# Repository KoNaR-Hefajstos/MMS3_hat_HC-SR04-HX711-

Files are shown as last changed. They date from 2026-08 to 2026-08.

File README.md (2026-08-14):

# Hat 4x HC-SR04 i Przetwornika Tensometrycznego HX711

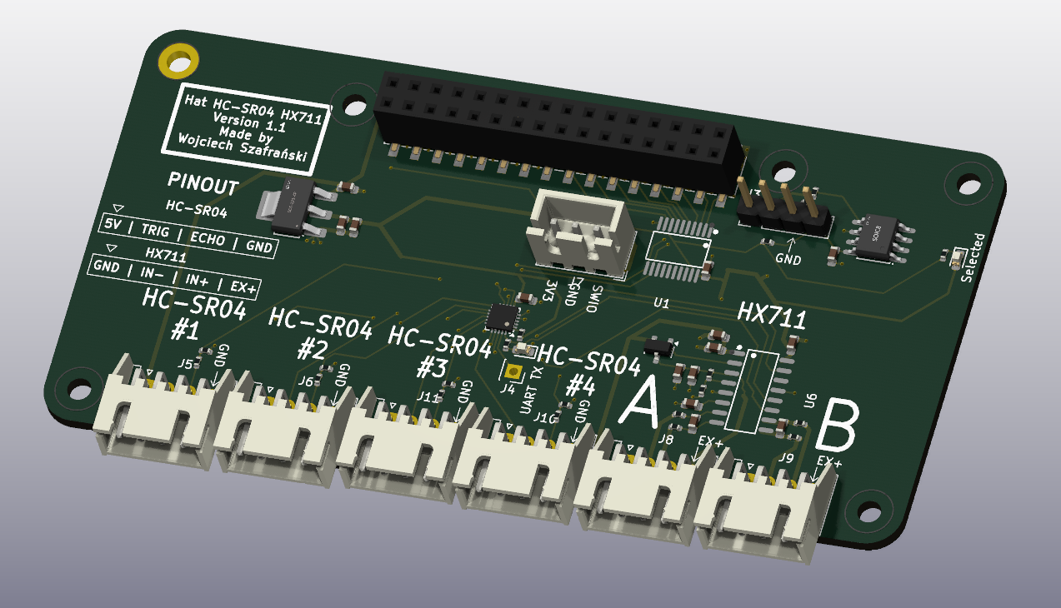
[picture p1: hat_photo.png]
zdjęcie


## Sekcja 1: Dokumentacja Hat'a

### Krótki opis projektu
Hat obsługuje cztery zewnętrzne ultradźwiękowe czujniki odległości HC-SR04 oraz dwukanałowey, 24-bitowego przetwornika dla belek tensometrycznych HX711.

Sercem modułu jest mikrokontroler **CH32V003**, który odczytuje dane z czujników i udostępnia je do odczytu po I2C

### Zgodność ze standardem ChainBus

* ✅ Używa złącza ChainBus, nie zmienia jego miejsca ani pinoutu.
* ✅ Używa wyłącznie interfejsu I2C do komunikacji zewnętrznej (działa jako Slave, nie inicjuje transmisji jako Master).
* ✅ Spełnia wymagania mechaniczne standardu (wymiary PCB, rozstaw otworów).
* ✅ Pobiera prąd mieszczący się w limitach wyznaczonych dla pojedynczego modułu (CH32V003 może wyzwalać czujniki ultradźwiękowe sekwencyjnie w celu redukcji zakłóceń i szpilek prądowych).
* ✅ Obsługuje napięcie wejściowe BRD_VIN do wartości 48V.

### Komunikacja i adresowanie

#### Adresacja I2C
Komunikacja z modułem nadrzędnym odbywa się przez magistralę I2C. Adres mikrokontrolera CH32V003 jest definiowany programowo.

| Układ (IC) | Funkcja | Adres I2C (7-bit) |
| :--- | :--- | :---: |
| **CH32V003** | Mikrokontroler (konwerter protokołów) | *Konfigurowalny w sofcie* |
| **M24C64-W** | Pamięć EEPROM (identyfikacja modułu)  | `1010000b` (0x50) |

### Pinout mikrokontrolera CH32V003

Rozprowadzenie sygnałów sterujących na piny mikrokontrolera przedstawia poniższa tabela:

| Pin MCU | Nazwa sygnału | Kierunek | Opis funkcjonalny |
| :--- | :--- | :---: | :--- |
| **PC0** | `ECHO #1` | Wejście  | Sygnał Echo z czujnika ultradźwiękowego nr 1 |
| **PC1** | `SDA` | Wej/Wyj  | Linia danych magistrali I2C (ChainBus) |
| **PC2** | `SCL` | Wejście  | Linia zegarowa magistrali I2C (ChainBus) |
| **PC3** | `TRIG #1` | Wyjście  | Sygnał wyzwalający (Trigger) dla czujnika nr 1 |
| **PC4** | `ECHO #2` | Wejście  | Sygnał Echo z czujnika ultradźwiękowego nr 2 |
| **PC5** | `TRIG #2` | Wyjście  | Sygnał wyzwalający (Trigger) dla czujnika nr 2 |
| **PC6** | `ECHO #3` | Wejście  | Sygnał Echo z czujnika ultradźwiękowego nr 3 |
| **PC7** | `TRIG #3` | Wyjście  | Sygnał wyzwalający (Trigger) dla czujnika nr 3 |
| **PD0** | `ECHO #4` | Wejście  | Sygnał Echo z czujnika ultradźwiękowego nr 4 |
| **PD2** | `TRIG #4` | Wyjście  | Sygnał wyzwalający (Trigger) dla czujnika nr 4 |
| **PD3** | `RATE_HX` | Wyjście  | Wybór prędkości próbkowania HX711 (`0` = 10 SPS, `1` = 80 SPS) |
| **PD4** | `PD_SCK_HX` | Wyjście  | Zegar transmisji oraz wyłączenie zasilania (Power Down) HX711  |
| **PD5** | `DEBUG_TX` | Wyjście  | Wyjście do debugowania (USART TX) |
| **PD6** | `DOUT_HX` | Wejście  | Wyjście danych szeregowych z przetwornika HX711 |

Dodatkowo na PD6 jest podłączona dioda, można jej użyć do debugowania
---

### Pinout złączy zewnętrznych

#### Złącza czujników ultradźwiękowych
Moduł posiada cztery  złącza w do podłączenia czujników odległości HC-SR04.

| Pin złącza | Nazwa sygnału | Opis |
| :---: | :--- | :--- |
| **1** | `5V` | Zasilanie czujnika (5V z magistrali ChainBus) |
| **2** | `TRIG` | Sygnał wyzwalający |
| **3** | `ECHO` | Sygnał powrotny |
| **4** | `GND` | Masa zasilania |

#### Złącze belki tensometrycznej (J5)
Złącze przeznaczone do podłączenia czujnika siły / wagi (belki tensometrycznej w układzie mostka Wheatstone'a). Sygnały wejściowe są dopasowane do specyfikacji Kanału B układu HX711.

| Pin złącza | Nazwa sygnału | Opis |
| :---: | :--- | :--- |
| **1** | `EX+` (E+) | Dodatnie napięcie zasilania mostka (Excitation +) |
| **2** | `INB+` | Dodatni sygnał wyjściowy z mostka (Input B+) |
| **3** | `INB-` | Ujemny sygnał wyjściowy z mostka (Input B-) |
| **4** | `GND` (E-) | Masa zasilania mostka (Excitation -) |

#### Złącze programowania mikrokontrolera (J7)
Złącze debugowania i programowania struktury CH32V003 przy użyciu WCH Link-E.

| Pin złącza | Nazwa sygnału | Opis |
| :---: | :--- | :--- |
| **1** | `SWIO` | Linia danych SWD (podłączona do pinu PD1 mikrokontrolera) |
| **2** | `GND` | Masa odniesienia |
| **3** | `3V3` | Zasilanie układu logiki (3.3V) |

---
### Szczegółowy opis działania układu

#### Sekcja ultradźwiękowa (HC-SR04)
Mikrokontroler CH32V003 cyklicznie generuje impuls wyzwalający piny `TRIG x`. Następnie mierzy czas trwania stanu wysokiego na powiązanym pinie `ECHO x`. Pomiar ten jest przeliczany na odległość zapisywany w rejestrach wewnętrznych MCU, gotowych do odczytu przez magistralę I2C.

#### Sekcja wagowa (HX711)
Układ HX711 przetwarza mikrowoltowe różnice napięć z mostka tensometrycznego na postać cyfrową.
* **Proces odczytu:** MCU monitoruje stan linii `DOUT_HX` (PD6). Gdy linia przejdzie w stan niski, oznacza to gotowość danych. Mikrokontroler taktuje linię `PD_SCK_HX` (PD4), odczytując kolejno 24 bity danych, a następnie generuje dodatkowe impulsy w celu konfiguracji następnego pomiaru (np. 26 impulsów, aby utrzymać odczyt z Kanału B ze wzmocnieniem 32).

#### Charakterystyka i parametry przetwornika HX711

Układ HX711 jest dedykowanym, 24-bitowym przetwornikiem ADC ze zintegrowanym niskoszumnym przedwzmacniaczem (PGA). Posiada on dwa różnicowe kanały wejściowe, które różnią się zakresem napięć oraz czułością:

#### Różnice między Kanałem A i Kanałem B

1. **Wzmocnienie i zakresy wejściowe (przy zasilaniu $V_{DD} = 5\text{V}$):**
   * **Kanał A:** Posiada programowalny stopień wzmocnienia równy **128** lub **64**.
     * Dla wzmocnienia **128**: zakres napięcia wejściowego wynosi **$\pm 20\text{ mV}$** (pełna skala). Jest to najbardziej czuły zakres, zalecany dla większości typowych belek tensometrycznych.
     * Dla wzmocnienia **64**: zakres napięcia wejściowego wynosi **$\pm 40\text{ mV}$**.
   * **Kanał B:** Posiada stałe, fabrycznie zdefiniowane wzmocnienie **32**.
     * Zakres napięcia wejściowego wynosi **$\pm 80\text{ mV}$**. Kanał ten, dzięki szerszemu zakresowi i mniejszej czułości, doskonale nadaje się do obsługi czujników o wyższym poziomie sygnału wyjściowego lub pomiarów pomocniczych.

2. **Wybór aktywnego kanału:**
   Multipleksacja kanałów wejściowych odbywa się programowo poprzez podanie odpowiedniej liczby impulsów zegarowych na pin `PD_SCK` po odczytaniu danych (wejście `DOUT` w stanie niskim):
   * **25 impulsów zegarowych:** następny pomiar na Kanale A ze wzmocnieniem 128,
   * **26 impulsów zegarowych:** następny pomiar na Kanale B ze wzmocnieniem 32,
   * **27 impulsów zegarowych:** następny pomiar na Kanale A ze wzmocnieniem 64.

3. **Częstotliwość próbkowania (SPS):**
   Prędkość konwersji jest ustawiana sprzętowo poprzez stan pinu `RATE_HX` (PD3):
   * Stan niski (`0`): **10 SPS** (próbek na sekundę). Zapewnia najniższy poziom szumów i najwyższą stabilność pomiarów wagowych (zalecane).
   * Stan wysoki (`1`): **80 SPS**. Zwiększa dynamikę pomiarów kosztem nieznacznego wzrostu szumu przetwornika.

---

---

### Gotowe arkusze hierarchiczne
W projekcie zaprojektowano i użyto następujących arkuszy hierarchicznych:
* **CH32v003** – Arkusz mikrokontrolera
* **Ultrasonic_HC-SR04** – Arkusz z podłączeniem HC-SR04 oraz dzielnikami napięcie 5V -> 3V3.
* **HX711_LoadCell** – Układ przetwornika HX711 ze wszytkimi elementami pasywnymi i złaczem

---

## Sekcja 2: Specyfikacja standardu ChainBus

### Architektura i łączenie modułów
Standard ChainBus umożliwia modułowe łączenie hatów. Na jednym MMS3 można zamontować pionowo **do 8 hat'ów**. Połączenie realizowane jest poprzez wpięcie złącza męskiego kolejnego hat'a w złącze żeńskie poprzedniego.

### Komunikacja i sterowanie
Magistrala ChainBus jest w pełni cyfrowa. Płyta główna nie steruje bezpośrednio sygnałami ogólnego przeznaczenia (GPIO) na poszczególnych hat'ach. Wszelkie operacje (np. odczyt czujników, sterowanie) muszą być realizowane przez dedykowane układy scalone komunikujące się przez interfejsy systemowe.

Wybór aktywnego modułu realizowany jest przez układ przełącznika magistrali (bus switch) na płycie głównej. Dzięki temu linie I2C, SPI i UART są niezależne dla każdego hat'a (brak konfliktów adresów I2C między różnymi hatami).
* **Identyfikacja:** Każdy moduł powinien posiadać pamięć EEPROM na magistrali I2C w celu identyfikacji płyty przez system - układ M24C64-W skonfigurowany na adres `1010000` przy liniach adresowych A0, A1, A2 zwartych do masy.

### Zasilanie
Złącze ChainBus dostarcza następujące linie zasilania:

| Magistrala zasilania | Napięcie znamionowe | Maksymalny prąd (łączny dla 8 hatów) | Szacowany prąd na jeden hat |
| :--- | :---: | :---: | :---: |
| **5V** | 5.0 V | 1.0 A | 125 mA |
| **12V stby** | 12.0 V | 0.5 A | 65 mA |
| **BRD_VIN** | 12.0 V – 48.0 V | 1.5 A | 185 mA |

*   Komponenty podłączone do linii `BRD_VIN` muszą być przystosowane do pracy z napięciem od 12V do **48 V**.

---

## Sekcja 3: Licencje

### Licencje projektu

*   **PCB:** CERN-OHL-P
*   **Software:** MIT License

[Template](https://github.com/KoNaR-Hefajstos/MMS3_hat_templates/) jest na licencji CC0 1.0 Universal. **Reszta projektu nie jest na tej licencji**

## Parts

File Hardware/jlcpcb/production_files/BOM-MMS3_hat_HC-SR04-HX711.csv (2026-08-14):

Comment | Designator | Footprint | LCSC | Quantity
100nF | C1,C10,C12,C13,C15,C16,C2,C6,C9 | C_0603 | C14663 | 9
100Ω | R13,R14,R15,R16 | R_0402 | C25076 | 4
10kΩ | R1,R11,R19,R21,R25,R5,R7,R9 | R_0402 | C25744 | 8
10uF | C11,C14,C3,C4,C5 | C_0603 | C19702 | 5
15kΩ | R20,R22,R6,R8 | R_0402 | C25756 | 4
20kΩ | R23 | R_0402 | C25765 | 1
330Ω | R12,R27 | R_0402 | C25104 | 2
8.2kΩ | R24 | R_0402 | C25924 | 1
AMS1117 | U3 | SOT-223-3_L6.5-W3.4-P2.30-LS7.0-BR | C6186 | 1
CH32V003F4U6 | U5 | QFN-20-1EP_3x3mm_P0.4mm_EP1.65x1.65mm | C5299908 | 1
HX711_C6705483 | U6 | SOP-16_L10.0-W3.9-P1.27-LS6.0-BL | C6705483 | 1
M24C64 | U2 | SOIC-8_L5.0-W4.0-P1.27-LS6.0-BL | C79988 | 1
MMBT3906 | Q3 | Q_SOT-23 | C7420354 | 1
Red | D3,D4 | D_0603 | C2286 | 2
SN74CB3Q3245PWR | U1 | TSSOP-20_L6.5-W4.4-P0.65-LS6.4-BL | C470961 | 1
Conn_01x04_Pin | J8 | JST_XH_S4B-XH-A_1x04_P2.50mm_Horizontal |  | 1
Debug_USART_TX | J4 | PinSocket_1x01_P2.54mm_Vertical |  | 1
Chainbus Out | J2 | PinSocket_2x16_P2.54mm_Vertical_SMD |  | 1
Conn_01x04_Pin | J3 | PinHeader_1x04_P2.54mm_Vertical |  | 1
Conn_01x04_Pin | J11 | JST_XH_S4B-XH-A_1x04_P2.50mm_Horizontal |  | 1
Conn_01x04_Pin | J10 | JST_XH_S4B-XH-A_1x04_P2.50mm_Horizontal |  | 1
Conn_01x04_Pin | J9 | JST_XH_S4B-XH-A_1x04_P2.50mm_Horizontal |  | 1
Program | J7 | JST_XH_B3B-XH-A_1x03_P2.50mm_Vertical |  | 1
Conn_01x04_Pin | J5 | JST_XH_S4B-XH-A_1x04_P2.50mm_Horizontal |  | 1
Conn_01x04_Pin | J6 | JST_XH_S4B-XH-A_1x04_P2.50mm_Horizontal |  | 1
Chainbus in | J1 | PinHeader_2x16_P2.54mm_Vertical_SMD |  | 1

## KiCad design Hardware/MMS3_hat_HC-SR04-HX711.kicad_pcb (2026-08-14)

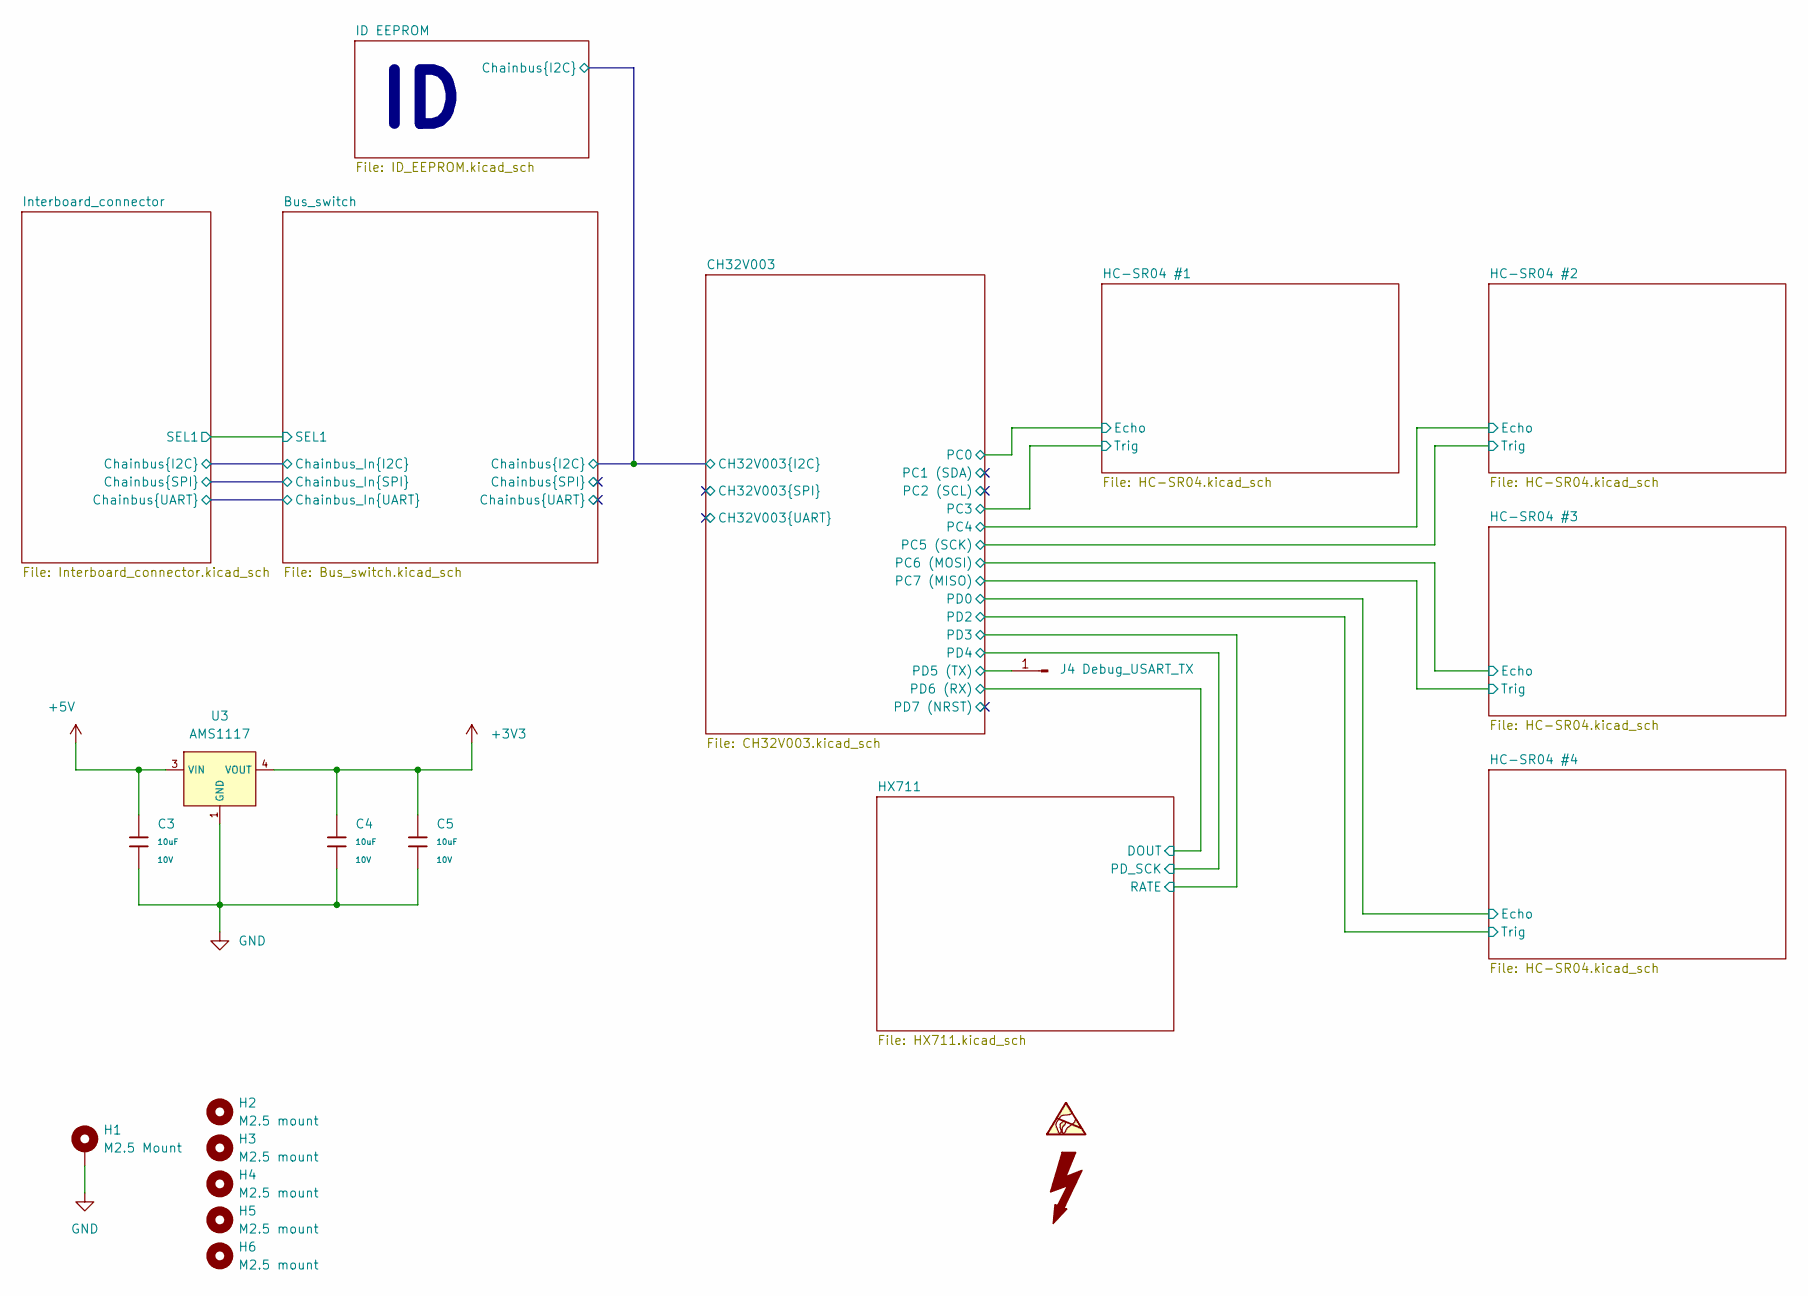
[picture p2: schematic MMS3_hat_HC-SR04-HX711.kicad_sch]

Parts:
C3, C4, C5: 10uF; C_0603; Voltage Rated 10V; Tolerance ±10%; Part CL10A106KP8NNNC; LCSC C19702
H1: M2.5 Mount; MountingHole_2.7mm_M2.5_DIN965_Pad_TopOnly
H2, H3, H4, H5, H6: M2.5 mount; MountingHole_2.7mm_M2.5
J4: Debug_USART_TX; PinSocket_1x01_P2.54mm_Vertical
U3: AMS1117; SOT-223-3_L6.5-W3.4-P2.30-LS7.0-BR; Output Voltage 3.3V; Dropout Voltage 1.3V@(800mA); Part AMS1117-3.3; LCSC C6186

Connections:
+3V3: C4.1, C5.1, U3.2 (VOUT), U3.4 (VOUT); also elsewhere on the board
+5V: C3.1, U3.3 (VIN); also elsewhere on the board
/CH32V003/CH32V003.TX: J4.1 (Pin_1_1); also elsewhere on the board
GND: C3.2, C4.2, C5.2, H1.1 (1_1), U3.1 (GND); also elsewhere on the board

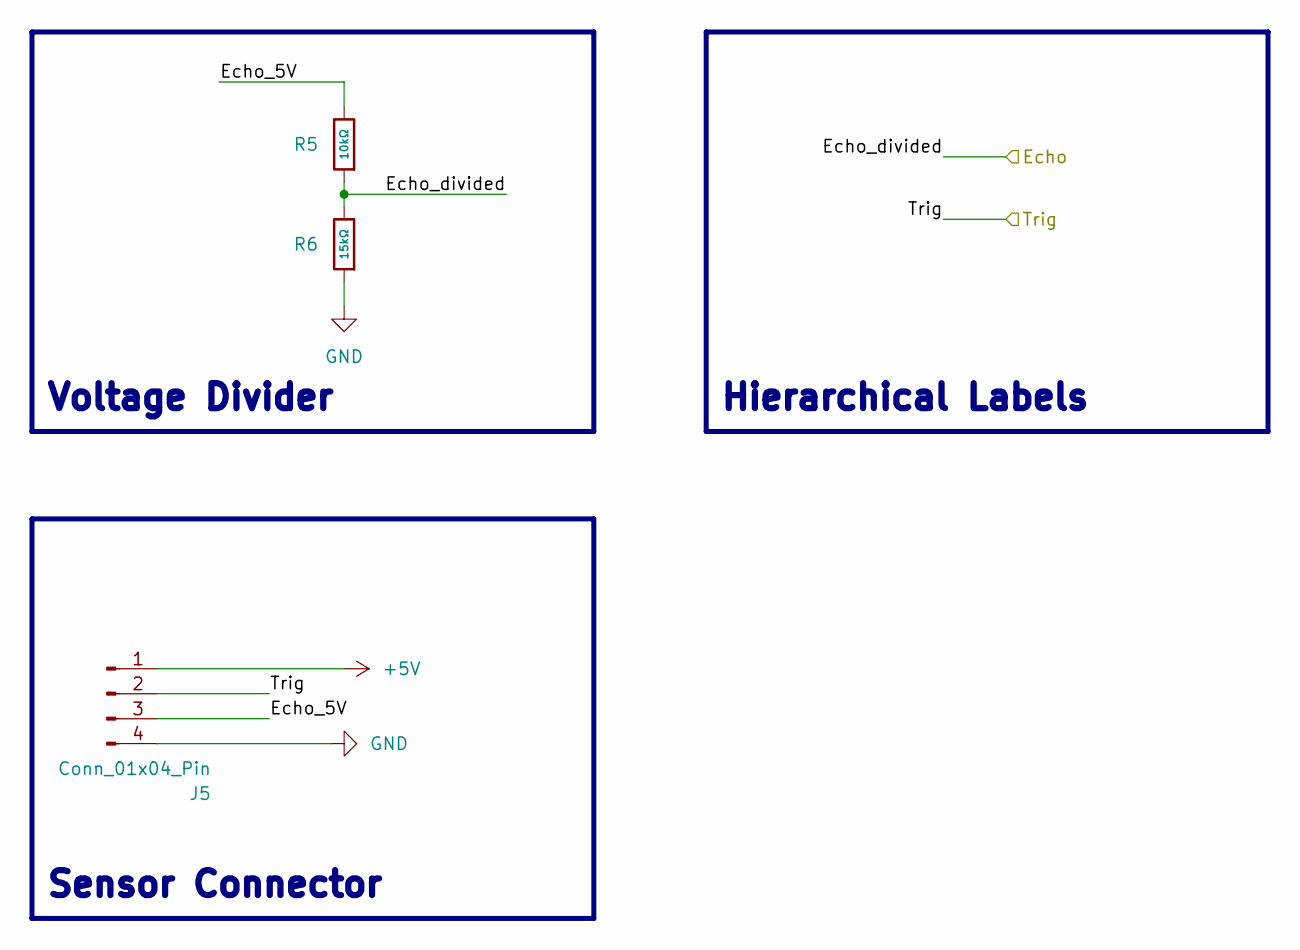
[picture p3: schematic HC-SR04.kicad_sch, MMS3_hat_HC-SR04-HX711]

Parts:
J5: Conn_01x04_Pin; JST_XH_S4B-XH-A_1x04_P2.50mm_Horizontal
R5: 10kΩ; R_0402; Overload Voltage (Max) 50V; Tolerance ±1%; Part 0402WGF1002TCE; LCSC C25744
R6: 15kΩ; R_0402; Overload Voltage (Max) 50V; Tolerance ±1%; Part 0402WGF1502TCE; LCSC C25756

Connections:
+5V: J5.1; also elsewhere on the board
/CH32V003/PC0: R5.1, R6.2; also elsewhere on the board
/CH32V003/PC3: J5.2; also elsewhere on the board
/HC-SR04 #1/Echo_5V: J5.3, R5.2
GND: J5.4, R6.1; also elsewhere on the board

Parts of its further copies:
J6, J10, J11: Conn_01x04_Pin; JST_XH_S4B-XH-A_1x04_P2.50mm_Horizontal
R7, R19, R21: 10kΩ; R_0402; Overload Voltage (Max) 50V; Tolerance ±1%; Part 0402WGF1002TCE; LCSC C25744
R8, R20, R22: 15kΩ; R_0402; Overload Voltage (Max) 50V; Tolerance ±1%; Part 0402WGF1502TCE; LCSC C25756

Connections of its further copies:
+5V: J6.1, J10.1, J11.1; also elsewhere on the board
/CH32V003/CH32V003.MISO: J11.2; also elsewhere on the board
/CH32V003/CH32V003.MOSI: R21.1, R22.2; also elsewhere on the board
/CH32V003/CH32V003.SCK: J6.2; also elsewhere on the board
/CH32V003/PC4: R7.1, R8.2; also elsewhere on the board
/CH32V003/PD0: R19.1, R20.2; also elsewhere on the board
/CH32V003/PD2: J10.2; also elsewhere on the board
/HC-SR04 #2/Echo_5V: J6.3, R7.2
/HC-SR04 #3/Echo_5V: J11.3, R21.2
/HC-SR04 #4/Echo_5V: J10.3, R19.2
GND: J6.4, J10.4, J11.4, R8.1, R20.1, R22.1; also elsewhere on the board

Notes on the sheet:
Voltage Divider
Sensor Connector
Hierarchical Labels

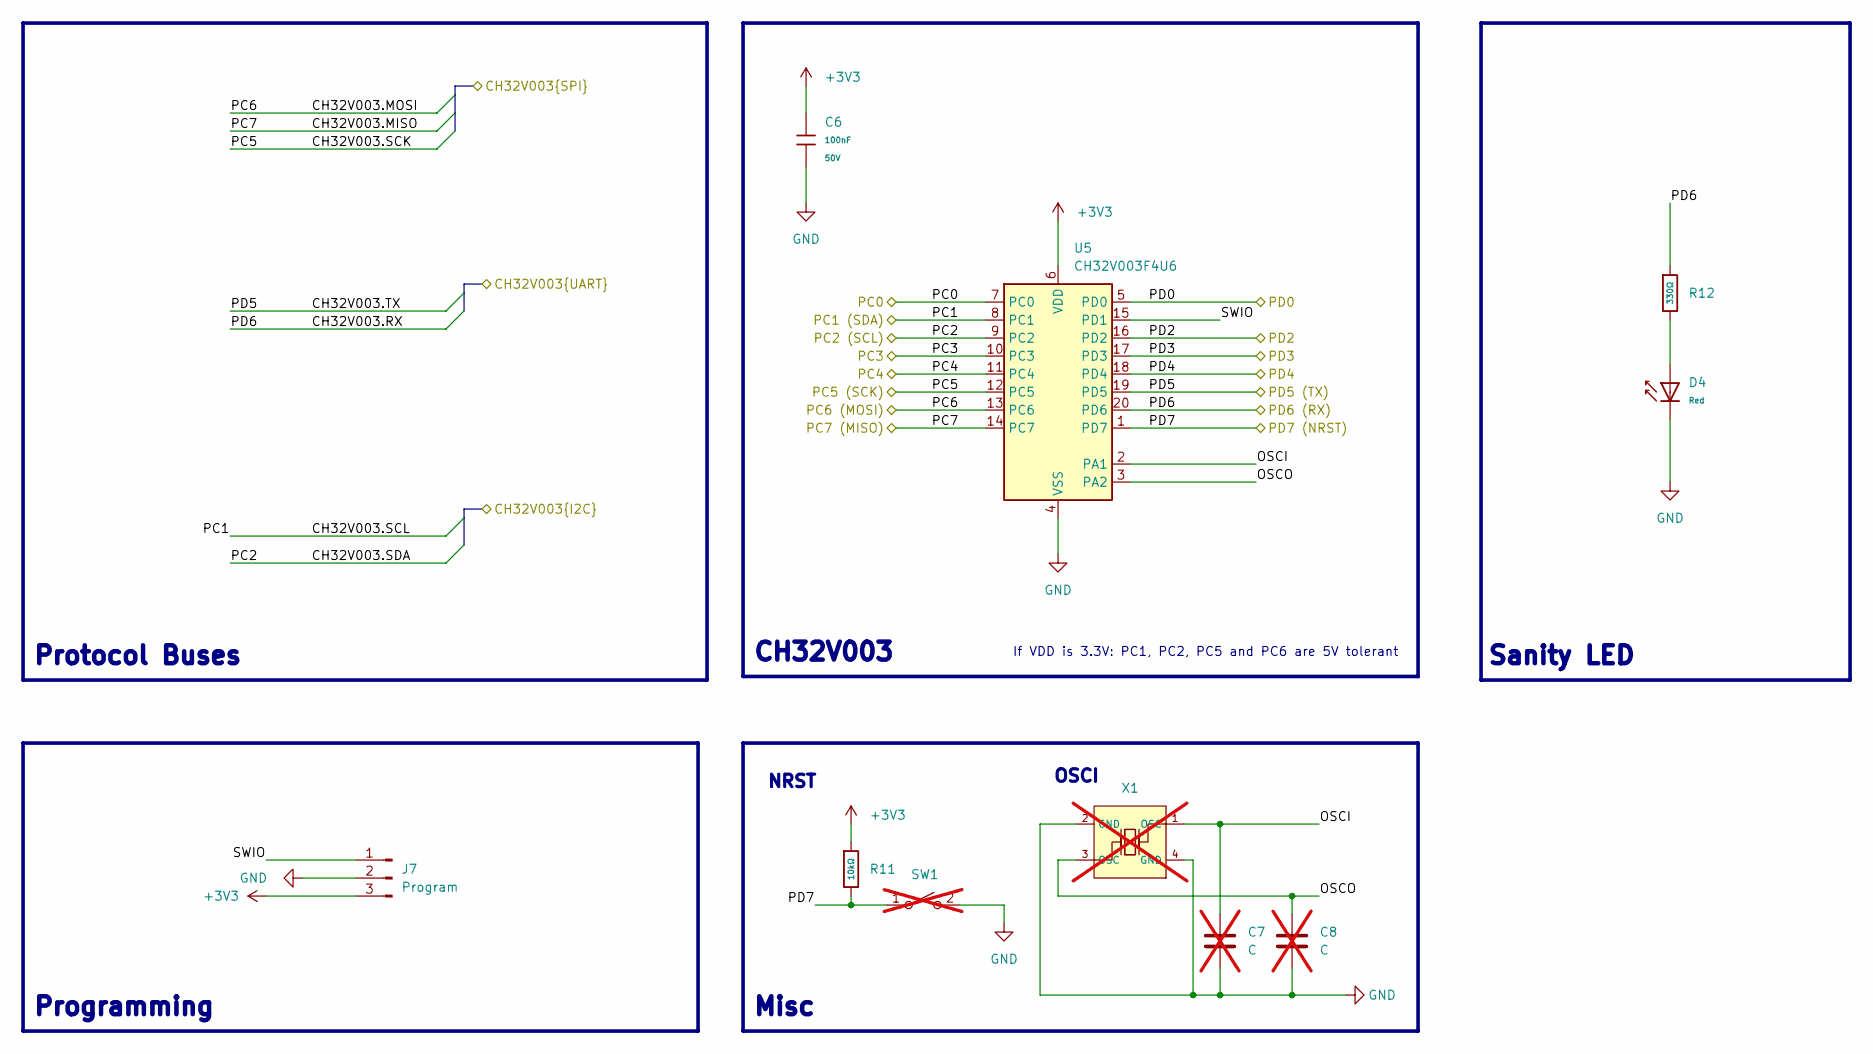
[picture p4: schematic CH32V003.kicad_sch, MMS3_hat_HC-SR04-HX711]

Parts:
C6: 100nF; C_0603; Voltage Rated 50V; Tolerance ±10%; Part CC0603KRX7R9BB104; LCSC C14663
C7, C8: C; not fitted
D4: Red; D_0603; Part KT-0603R; LCSC C2286
J7: Program; JST_XH_B3B-XH-A_1x03_P2.50mm_Vertical
R11: 10kΩ; R_0402; Overload Voltage (Max) 50V; Tolerance ±1%; Part 0402WGF1002TCE; LCSC C25744
R12: 330Ω; R_0402; Overload Voltage (Max) 50V; Tolerance ±1%; Part 0402WGF3300TCE; LCSC C25104
SW1: SW_SPST; not fitted
U5: CH32V003F4U6; QFN-20-1EP_3x3mm_P0.4mm_EP1.65x1.65mm; LCSC C5299908
X1: X322525MOB4SI; OSC-SMD_4P-L3.2-W2.5-BL; Frequency Tolerance ±10ppm; Part X322525MOB4SI; LCSC C9006; not fitted

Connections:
+3V3: C6.1, J7.3, R11.1, U5.6 (VDD); also elsewhere on the board
/Bus_switch/Chainbus.SCL: U5.8 (PC1); also elsewhere on the board
/Bus_switch/Chainbus.SDA: U5.9 (PC2); also elsewhere on the board
/CH32V003/CH32V003.MISO: U5.14 (PC7); also elsewhere on the board
/CH32V003/CH32V003.MOSI: U5.13 (PC6); also elsewhere on the board
/CH32V003/CH32V003.RX: R12.1, U5.20 (PD6); also elsewhere on the board
/CH32V003/CH32V003.SCK: U5.12 (PC5); also elsewhere on the board
/CH32V003/CH32V003.TX: U5.19 (PD5); also elsewhere on the board
/CH32V003/OSCI: C7.1, U5.2 (PA1), X1.1 (OSC)
/CH32V003/OSCO: C8.1, U5.3 (PA2), X1.3 (OSC)
/CH32V003/PC0: U5.7 (PC0); also elsewhere on the board
/CH32V003/PC3: U5.10 (PC3); also elsewhere on the board
/CH32V003/PC4: U5.11 (PC4); also elsewhere on the board
/CH32V003/PD0: U5.5 (PD0); also elsewhere on the board
/CH32V003/PD2: U5.16 (PD2); also elsewhere on the board
/CH32V003/PD3: U5.17 (PD3); also elsewhere on the board
/CH32V003/PD4: U5.18 (PD4); also elsewhere on the board
/CH32V003/PD7: R11.2, SW1.1 (A), U5.1 (PD7)
/CH32V003/SWIO: J7.1, U5.15 (PD1)
GND: C6.2, C7.2, C8.2, D4.1, J7.2, SW1.2 (B), U5.4 (VSS), U5.21 (VSS), X1.2 (GND), X1.4 (GND); also elsewhere on the board
unnamed: D4.2, R12.2

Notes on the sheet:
NRST
Sanity LED
If VDD is 3.3V: PC1, PC2, PC5 and PC6 are 5V tolerant
CH32V003
OSCI
Protocol Buses
Misc
Programming

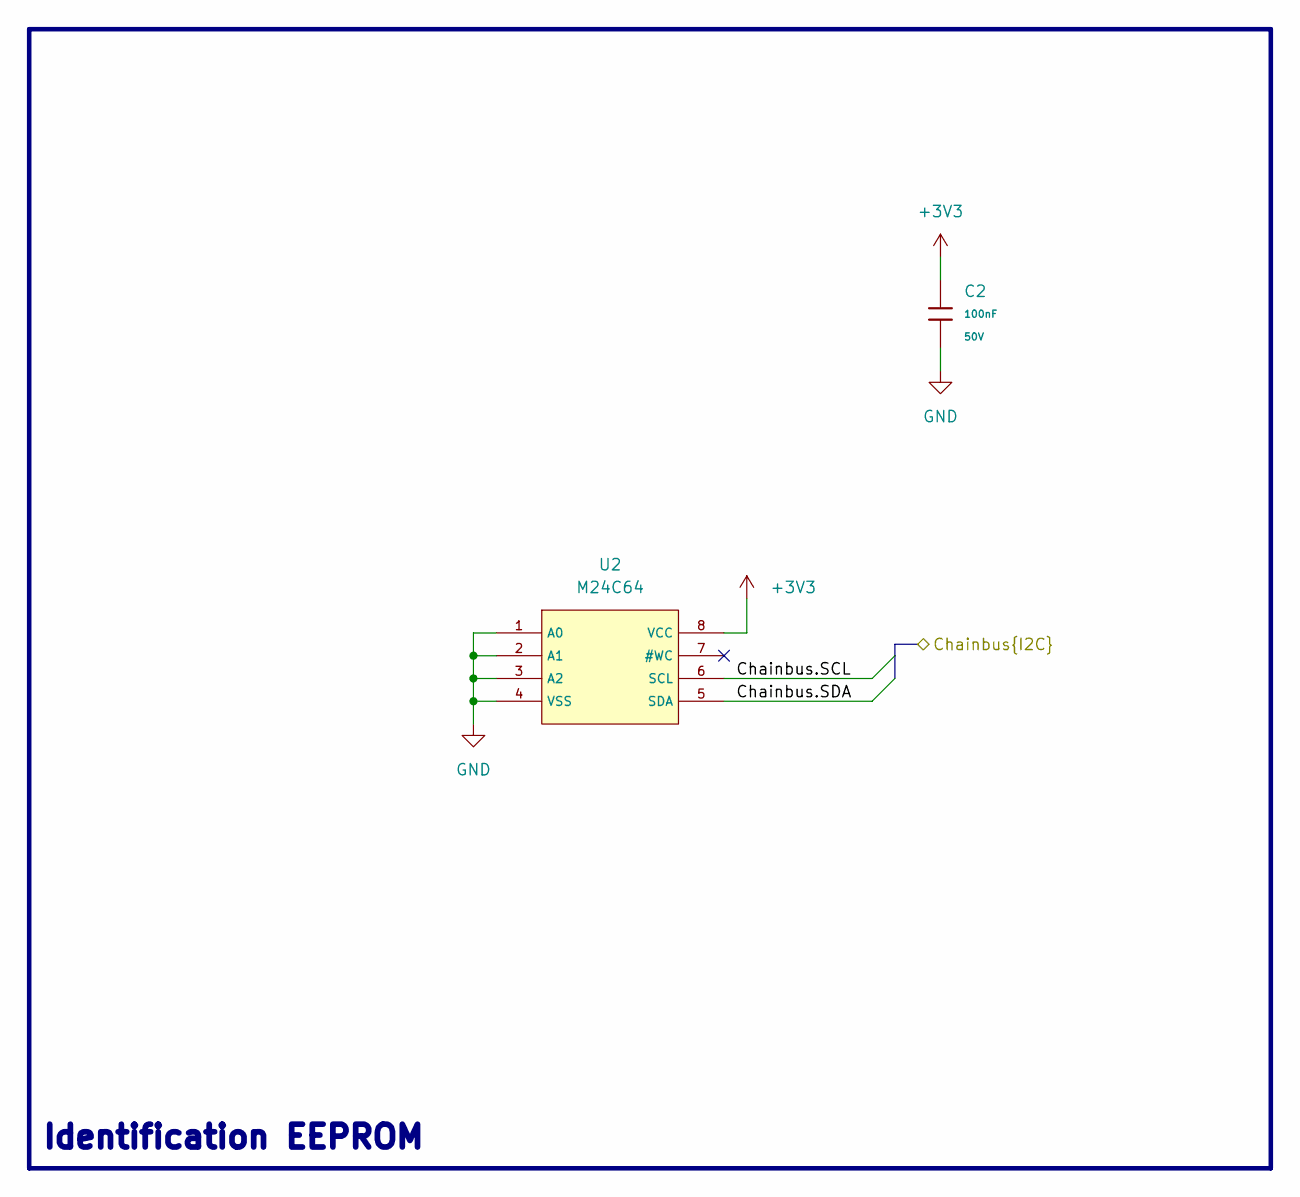
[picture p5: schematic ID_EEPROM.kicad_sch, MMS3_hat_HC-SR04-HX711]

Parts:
C2: 100nF; C_0603; Voltage Rated 50V; Tolerance ±10%; Part CC0603KRX7R9BB104; LCSC C14663
U2: M24C64; SOIC-8_L5.0-W4.0-P1.27-LS6.0-BL; Supply Voltage 1.8V~5.5V; Part M24C64-RMN6TP; LCSC C79988

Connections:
+3V3: C2.1, U2.8 (VCC); also elsewhere on the board
/Bus_switch/Chainbus.SCL: U2.6 (SCL); also elsewhere on the board
/Bus_switch/Chainbus.SDA: U2.5 (SDA); also elsewhere on the board
GND: C2.2, U2.1 (A0), U2.2 (A1), U2.3 (A2), U2.4 (VSS); also elsewhere on the board

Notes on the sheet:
Identification EEPROM

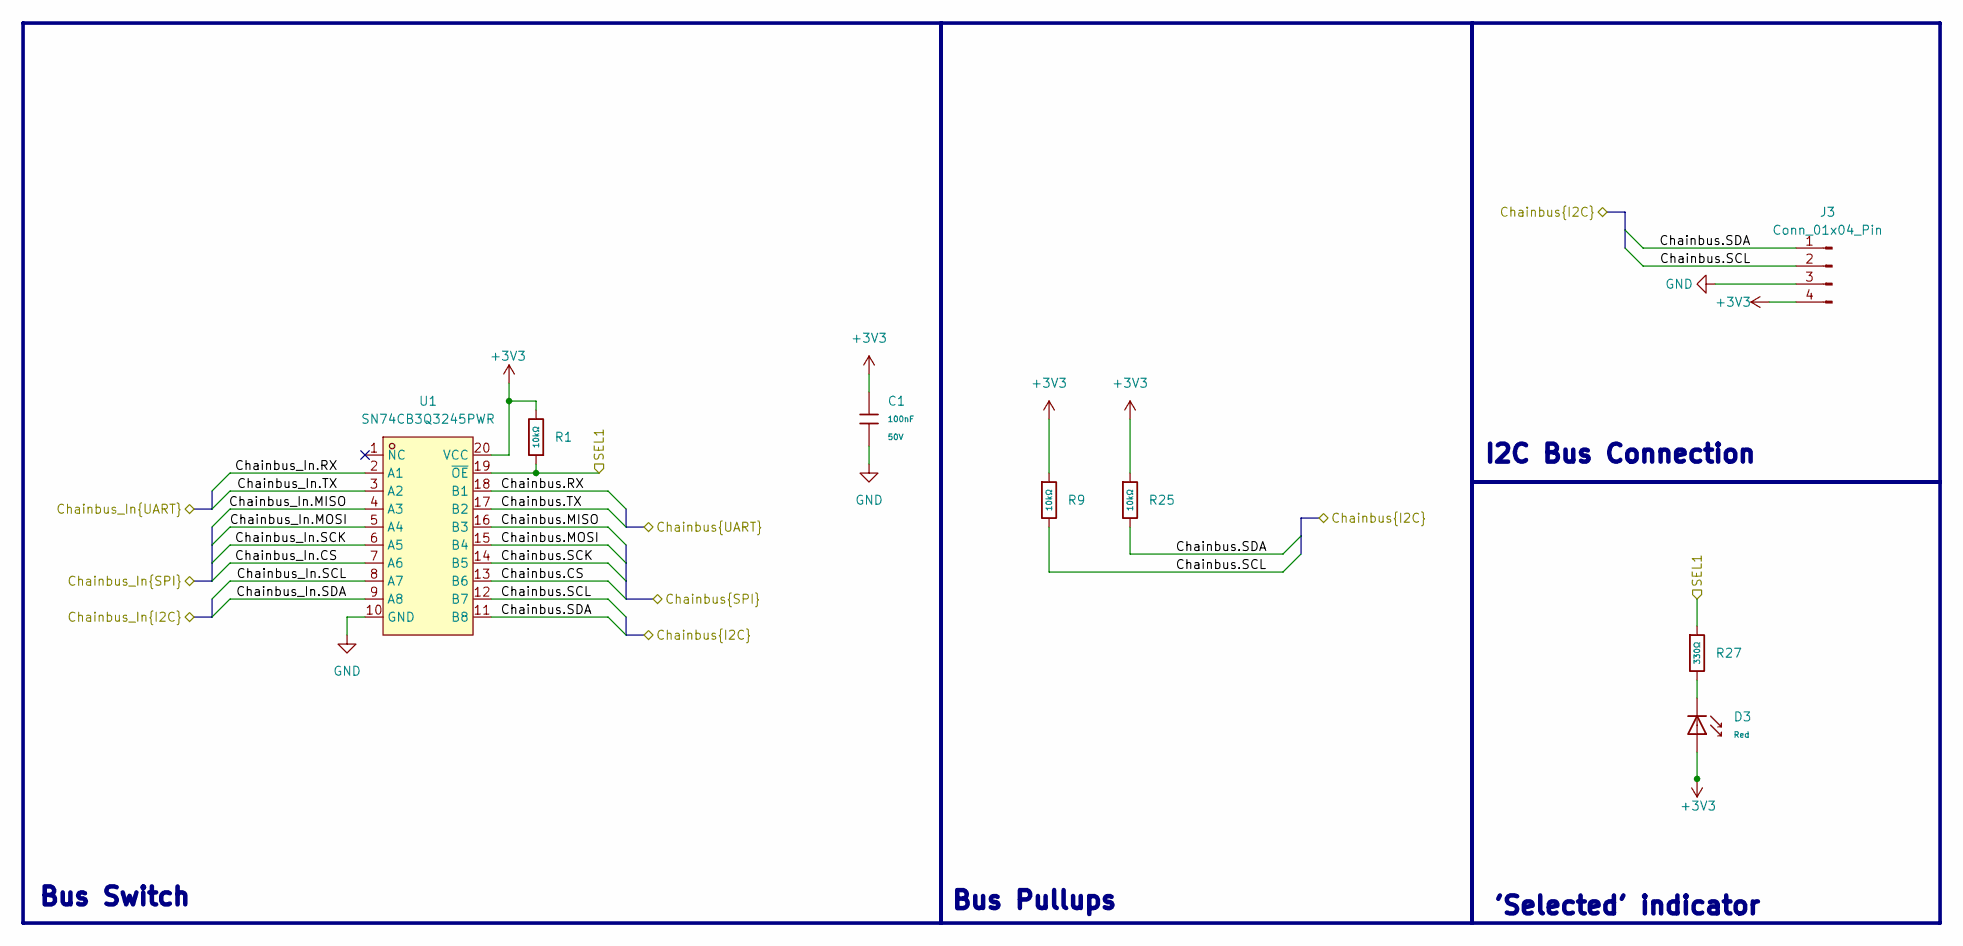
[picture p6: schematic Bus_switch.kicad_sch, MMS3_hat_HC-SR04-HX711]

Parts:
C1: 100nF; C_0603; Voltage Rated 50V; Tolerance ±10%; Part CC0603KRX7R9BB104; LCSC C14663
D3: Red; D_0603; Part KT-0603R; LCSC C2286
J3: Conn_01x04_Pin; PinHeader_1x04_P2.54mm_Vertical
R1, R9, R25: 10kΩ; R_0402; Overload Voltage (Max) 50V; Tolerance ±1%; Part 0402WGF1002TCE; LCSC C25744
R27: 330Ω; R_0402; Overload Voltage (Max) 50V; Tolerance ±1%; Part 0402WGF3300TCE; LCSC C25104
U1: SN74CB3Q3245PWR; TSSOP-20_L6.5-W4.4-P0.65-LS6.4-BL; MPN SN74CB3Q3245PWR; LCSC Part C470961

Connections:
+3V3: C1.1, D3.2, J3.4, R1.2, R9.1, R25.1, U1.20 (VCC); also elsewhere on the board
/Bus_switch/Chainbus.CS: U1.13 (B6)
/Bus_switch/Chainbus.MISO: U1.16 (B3)
/Bus_switch/Chainbus.MOSI: U1.15 (B4)
/Bus_switch/Chainbus.RX: U1.18 (B1)
/Bus_switch/Chainbus.SCK: U1.14 (B5)
/Bus_switch/Chainbus.SCL: J3.2, R9.2, U1.12 (B7); also elsewhere on the board
/Bus_switch/Chainbus.SDA: J3.1, R25.2, U1.11 (B8); also elsewhere on the board
/Bus_switch/Chainbus.TX: U1.17 (B2)
/Bus_switch/Chainbus_In.CS: U1.7 (A6); also elsewhere on the board
/Bus_switch/Chainbus_In.MISO: U1.4 (A3); also elsewhere on the board
/Bus_switch/Chainbus_In.MOSI: U1.5 (A4); also elsewhere on the board
/Bus_switch/Chainbus_In.RX: U1.2 (A1); also elsewhere on the board
/Bus_switch/Chainbus_In.SCK: U1.6 (A5); also elsewhere on the board
/Bus_switch/Chainbus_In.SCL: U1.8 (A7); also elsewhere on the board
/Bus_switch/Chainbus_In.SDA: U1.9 (A8); also elsewhere on the board
/Bus_switch/Chainbus_In.TX: U1.3 (A2); also elsewhere on the board
/Bus_switch/SEL1: R1.1, R27.1, U1.19 (~OE); also elsewhere on the board
GND: C1.2, J3.3, U1.10 (GND); also elsewhere on the board
unnamed: D3.1, R27.2

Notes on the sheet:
Bus Switch
Bus Pullups
'Selected' indicator
I2C Bus Connection

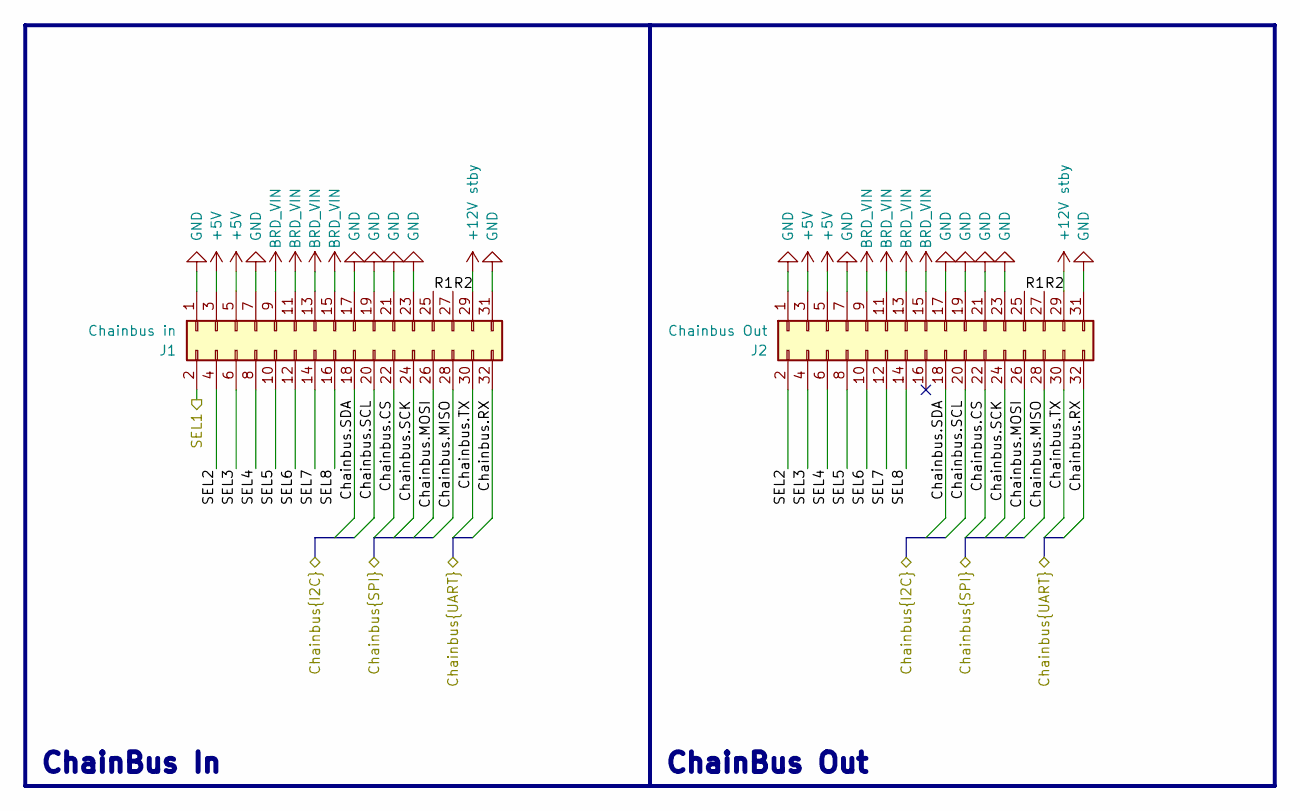
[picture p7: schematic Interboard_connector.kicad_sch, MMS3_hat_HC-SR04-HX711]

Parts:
J1: Chainbus in; PinHeader_2x16_P2.54mm_Vertical_SMD
J2: Chainbus Out; PinSocket_2x16_P2.54mm_Vertical_SMD

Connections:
+5V: J1.3, J1.5, J2.3, J2.5; also elsewhere on the board
+12V stby: J1.29, J2.29
/Bus_switch/Chainbus_In.CS: J1.22, J2.22; also elsewhere on the board
/Bus_switch/Chainbus_In.MISO: J1.28, J2.28; also elsewhere on the board
/Bus_switch/Chainbus_In.MOSI: J1.26, J2.26; also elsewhere on the board
/Bus_switch/Chainbus_In.RX: J1.32, J2.32; also elsewhere on the board
/Bus_switch/Chainbus_In.SCK: J1.24, J2.24; also elsewhere on the board
/Bus_switch/Chainbus_In.SCL: J1.20, J2.20; also elsewhere on the board
/Bus_switch/Chainbus_In.SDA: J1.18, J2.18; also elsewhere on the board
/Bus_switch/Chainbus_In.TX: J1.30, J2.30; also elsewhere on the board
/Bus_switch/SEL1: J1.2; also elsewhere on the board
/Interboard_connector/R1: J1.25, J2.25
/Interboard_connector/R2: J1.27, J2.27
/Interboard_connector/SEL2: J1.4, J2.2
/Interboard_connector/SEL3: J1.6, J2.4
/Interboard_connector/SEL4: J1.8, J2.6
/Interboard_connector/SEL5: J1.10, J2.8
/Interboard_connector/SEL6: J1.12, J2.10
/Interboard_connector/SEL7: J1.14, J2.12
/Interboard_connector/SEL8: J1.16, J2.14
BRD_VIN: J1.9, J1.11, J1.13, J1.15, J2.9, J2.11, J2.13, J2.15
GND: J1.1, J1.7, J1.17, J1.19, J1.21, J1.23, J1.31, J2.1, J2.7, J2.17, J2.19, J2.21, J2.23, J2.31; also elsewhere on the board

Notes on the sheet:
ChainBus In
ChainBus Out

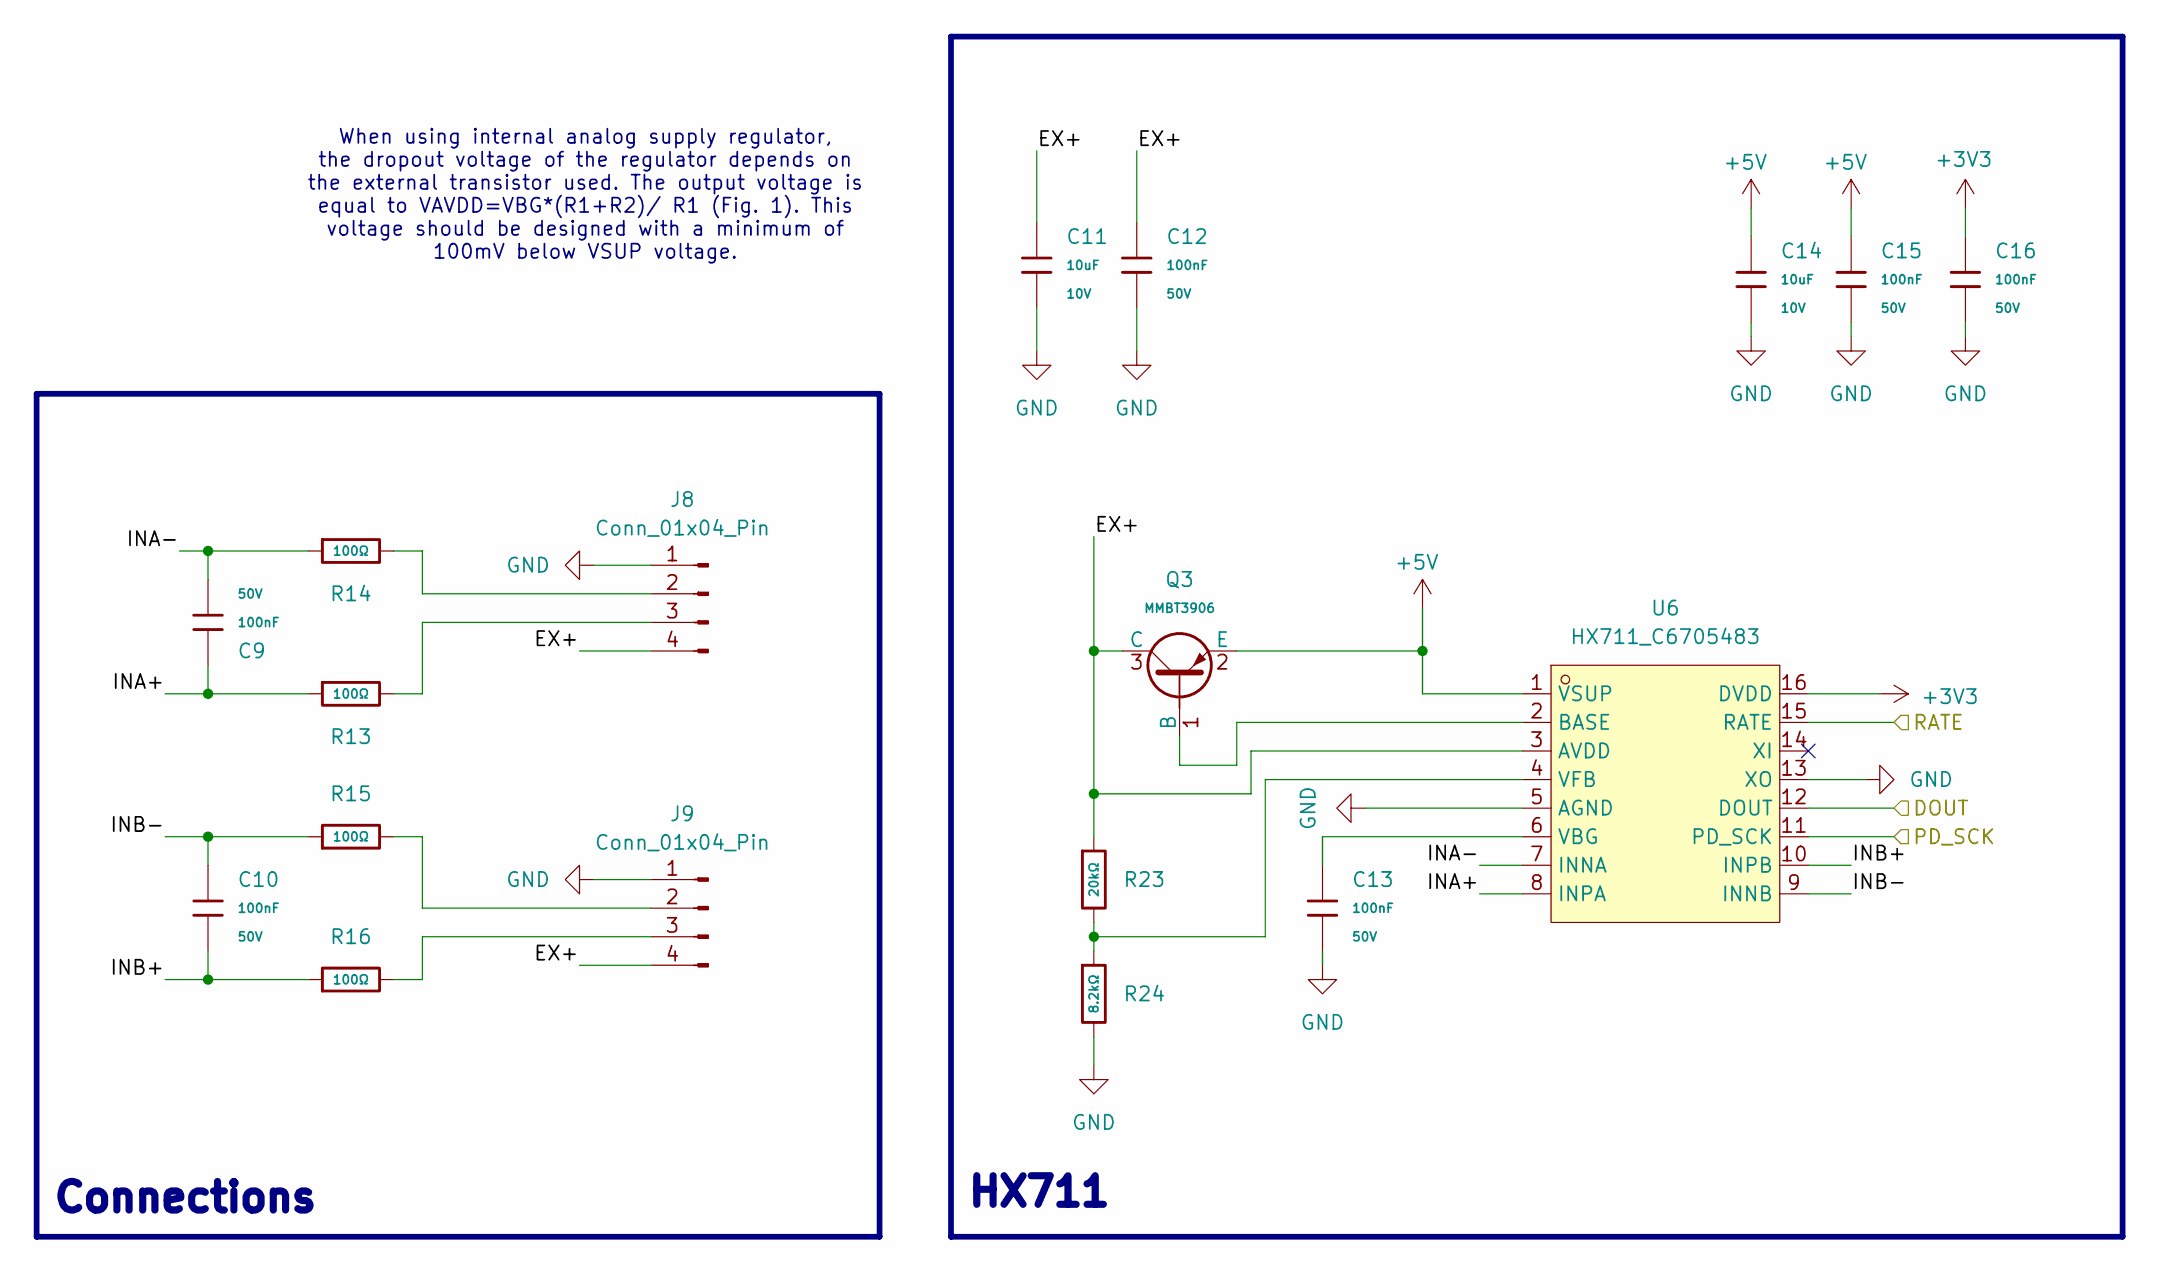
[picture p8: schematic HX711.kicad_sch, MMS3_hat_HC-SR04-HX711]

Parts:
C9, C10, C12, C13, C15, C16: 100nF; C_0603; Voltage Rated 50V; Tolerance ±10%; Part CC0603KRX7R9BB104; LCSC C14663
C11, C14: 10uF; C_0603; Voltage Rated 10V; Tolerance ±10%; Part CL10A106KP8NNNC; LCSC C19702
J8, J9: Conn_01x04_Pin; JST_XH_S4B-XH-A_1x04_P2.50mm_Horizontal
Q3: MMBT3906; Q_SOT-23; Part MMBT3906; LCSC C7420354
R13, R14, R15, R16: 100Ω; R_0402; Overload Voltage (Max) 50V; Tolerance ±1%; Part 0402WGF1000TCE; LCSC C25076
R23: 20kΩ; R_0402; Overload Voltage (Max) 50V; Tolerance ±1%; Part 0402WGF2002TCE; LCSC C25765
R24: 8.2kΩ; R_0402; Overload Voltage (Max) 50V; Tolerance ±1%; Part 0402WGF8201TCE; LCSC C25924
U6: HX711_C6705483; SOP-16_L10.0-W3.9-P1.27-LS6.0-BL; MPN HX711; LCSC Part C6705483

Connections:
+3V3: C16.1, U6.16 (DVDD); also elsewhere on the board
+5V: C14.1, C15.1, Q3.2 (E), U6.1 (VSUP); also elsewhere on the board
/CH32V003/CH32V003.RX: U6.12 (DOUT); also elsewhere on the board
/CH32V003/PD3: U6.15 (RATE); also elsewhere on the board
/CH32V003/PD4: U6.11 (PD_SCK); also elsewhere on the board
/HX711/EX+: C11.1, C12.1, J8.4, J9.4, Q3.3 (C), R23.1, U6.3 (AVDD)
/HX711/INA+: C9.1, R13.1, U6.8 (INPA)
/HX711/INA-: C9.2, R14.1, U6.7 (INNA)
/HX711/INB+: C10.2, R16.1, U6.10 (INPB)
/HX711/INB-: C10.1, R15.1, U6.9 (INNB)
GND: C11.2, C12.2, C13.2, C14.2, C15.2, C16.2, J8.1, J9.1, R24.2, U6.5 (AGND), U6.13 (XO); also elsewhere on the board
unnamed: J8.2, R14.2
unnamed: J8.3, R13.2
unnamed: J9.2, R15.2
unnamed: J9.3, R16.2
unnamed: Q3.1 (B), U6.2 (BASE)
unnamed: C13.1, U6.6 (VBG)
unnamed: R23.2, R24.1, U6.4 (VFB)

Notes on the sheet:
Connections
When using internal analog supply regulator, the dropout voltage of the regulator depends on the external transistor used. The output voltage is equal to VAVDD=VBG*(R1+R2)/ R1 (Fig. 1). This voltage should be designed with a minimum of 100mV below VSUP voltage.
HX711

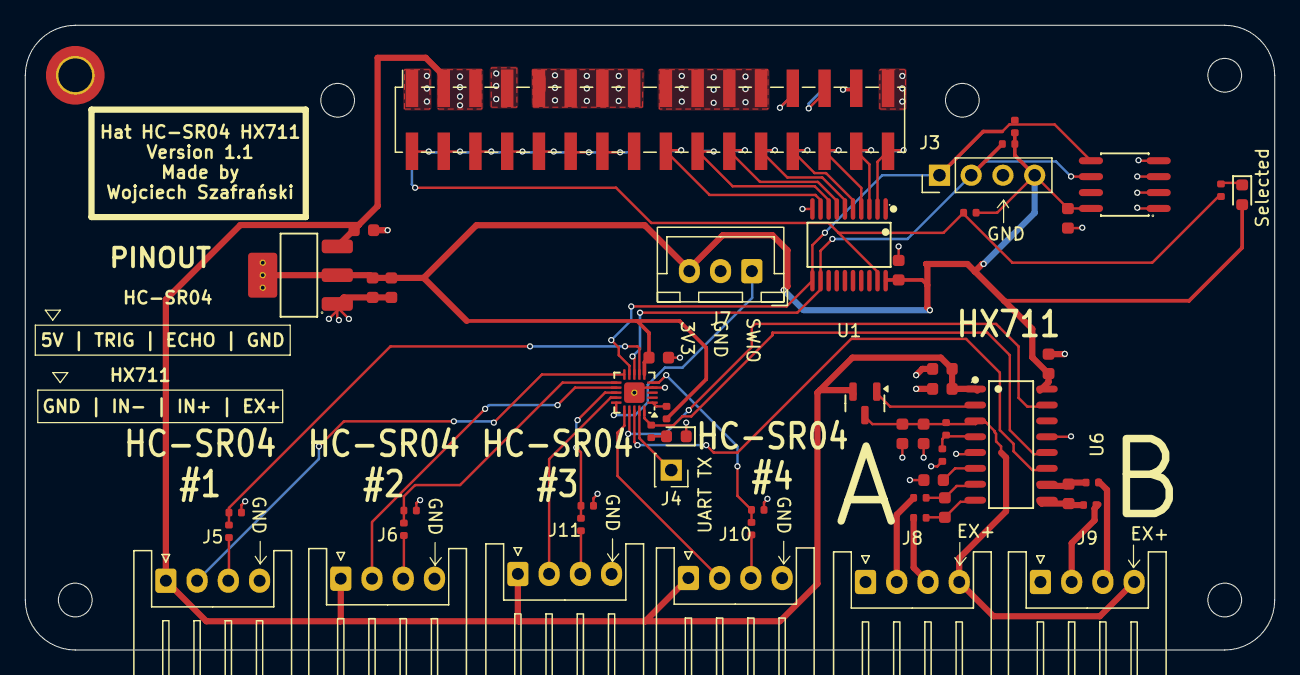
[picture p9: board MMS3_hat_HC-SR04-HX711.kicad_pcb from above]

Board: 2 copper layers, 100.0 x 50.0 mm, 59 parts (1 on the bottom side), 57 nets.

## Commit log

2026-03-01 finished schematic
    [CH32V003.kicad_sch, HC-SR04.kicad_sch, HX711.kicad_sch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]
2026-03-01 finished routing and exported gerber
    [BOM-MMS3_hat_HC-SR04-HX711.csv, CH32V003.kicad_sch, HC-SR04.kicad_sch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]
2026-04-08 updated bus switch to sensible one
    [BOM-MMS3_hat_HC-SR04-HX711.csv, Bus_switch.kicad_sch, HC-SR04.kicad_sch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]
2026-04-08 rounded da corners
    [CPL-MMS3_hat_HC-SR04-HX711.csv, MMS3_hat_HC-SR04-HX711-CuBottom.gbr, MMS3_hat_HC-SR04-HX711-CuTop.gbr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]
2026-04-11 Added version number
    [MMS3_hat_HC-SR04-HX711.kicad_pcb]
2026-04-18 fixed selected led polarity
    [BOM-MMS3_hat_HC-SR04-HX711.csv, Bus_switch.kicad_sch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]
2026-04-18 made pinout on silkscreen nicer
    [MMS3_hat_HC-SR04-HX711-CuBottom.gbr, MMS3_hat_HC-SR04-HX711-CuTop.gbr, MMS3_hat_HC-SR04-HX711-EdgeCuts.gbr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]
2026-04-20 generated final gerber
    [BOM-MMS3_hat_HC-SR04-HX711.csv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]
2026-06-08 BREAKING: updated CH32 programming pinout
    [BOM-MMS3_hat_HC-SR04-HX711.csv, Bus_switch.kicad_sch, CH32V003.kicad_sch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]
2026-06-10 added documentation
    [BOM-MMS3_hat_HC-SR04-HX711.csv, Bus_switch.kicad_sch, CH32V003.kicad_sch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]
2026-08-14 added photo
    [BOM-MMS3_hat_HC-SR04-HX711.csv, CH32V003.kicad_sch, Interboard_connector.kicad_sch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]
